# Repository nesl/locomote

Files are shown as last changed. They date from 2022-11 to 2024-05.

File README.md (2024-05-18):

# LocoMote: AI-driven Sensor Tags for Fine-Grained Undersea Localization and Sensing

hardware_setup
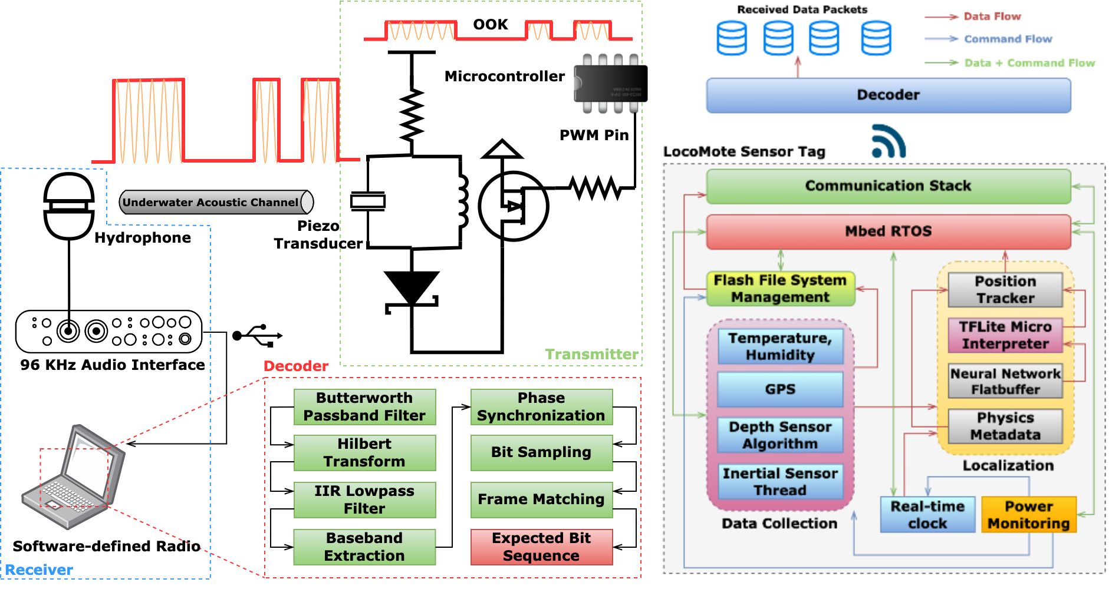
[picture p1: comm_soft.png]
software_setup


## Paper
https://ieeexplore.ieee.org/abstract/document/10494218/

## Summary
Long-term and fine-grained maritime localization and sensing is challenging due to sporadic connectivity, constrained power budget, limited footprint, and hostile environment. In this paper, we present the design considerations and implementation of LocoMote, a rugged ultra-low-footprint undersea sensor tag with on-device AI-driven localization, online communication, and energy-harvesting capabilities. LocoMote uses on-chip (< 30 kB) neural networks to track underwater objects within 3 meters with ~6 minutes of GPS outage from 9DoF inertial sensor readings. The tag streams data at 2-5 kbps (< 10^-3 bit error rate) using piezo-acoustic ultrasonics, achieving underwater communication range of more than 50 meters while allowing up to 55 nodes to concurrently stream via randomized time-division multiple access. To recharge the battery during sleep, the tag uses an aluminum-air salt water energy harvesting system, generating upto 5 mW of power. LocoMote is ultra-lightweight (< 50 grams), tiny (32x32$x10 mm^3), consumes low power (~330 mW peak), and comes with a suite of high-resolution sensors. We highlight the hardware and software design decisions, implementation lessons, and the real-world performance of our tag versus existing oceanic sensing technologies. 

## Code Architecture
- ```encasement```: contains the ```.stl``` CAD files for the EPU-40 encasement and resin base.
- ```pcb```: contains the altium pcb design files for the main circuit board, and eagle pcb design files for the offline battery charger and pressure sensor board. PCB schematic and board design images are also provided.
- ```software```: contains code for: (a) data logging from all the sensors into the flash, also contains code to toggle data recovery modes from a computer using a Python script (```data_logger_demo```); (b) communication stack for the transmitter and receiver (```piezo_OOK_demo```); (c) PWM demo for piezo (```piezo_PWM_demo```); (d) GPS data logging and power measurement (```GPS```); (e) repository link for developing neural inertial navigation algorithms, as well as Marina Del Rey deployment IMU, GPS dataset; an importer is provided for the dataset (```neural_inertial_navigation```).

## Required items
- Altium Designer (21.x.x or higher) (https://www.altium.com/altium-designer/).
- AutoDesk Eagle (9.6.2 or higher) (https://www.autodesk.com/products/eagle/overview)
- TinkerCad (https://www.tinkercad.com/).
- For developing neural inertial navigation algorithms, check the requirements in ```software/neural_inertial_navigation/tinyodom```.
- MATLAB with all toolboxes installed (R2020a or better).
- Arduino IDE (https://www.arduino.cc/en/software/) with STM32 Core installed (https://github.com/stm32duino/Arduino_Core_STM32). The Arduino libraries required are listed in ```software/arduino_lib_links.txt```.
- Audacity (https://www.audacityteam.org/)
- Hardware: Check the pcb design files and the paper for list of hardware required and purchase links.

## Citation
Please cite this as:

Swapnil Sayan Saha, Caden Davis, Sandeep Singh Sandha, Junha Park, Joshua Geronimo, Luis Antonio Garcia and Mani Srivastava, "LocoMote: AI-driven Sensor Tags for Fine-Grained Undersea Localization and Sensing", in IEEE Sensors Journal, vol. 24, no. 10, pp. 16999-17018, 15 May 2024, IEEE.

## Acknowledgements
 This work was sponsored in part by: the IoBT REIGN Collaborative Research Alliance funded by the Army Research Laboratory under Cooperative Agreement W911NF-17-2-0196; the Air Force Office of Scientific Research under award FA9550-22-1-0193; the CONIX Research Center, one of the centers in Joint University Microelectronics Program, a Semiconductor Research Corporation program sponsored by the Defense Advanced Research Projects Agency; and, the King Abdullah University of Science and Technology through its Sensor Innovation research program.

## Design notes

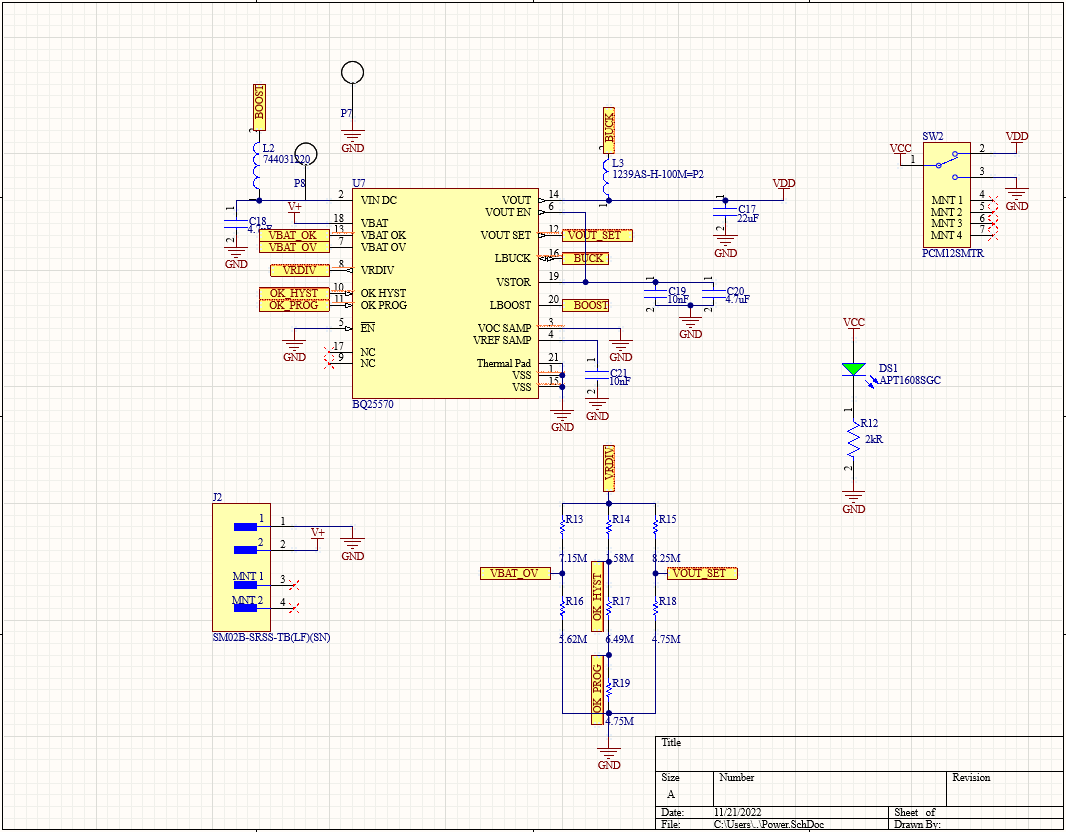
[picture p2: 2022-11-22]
pcb/schematic images/power_schematic.PNG

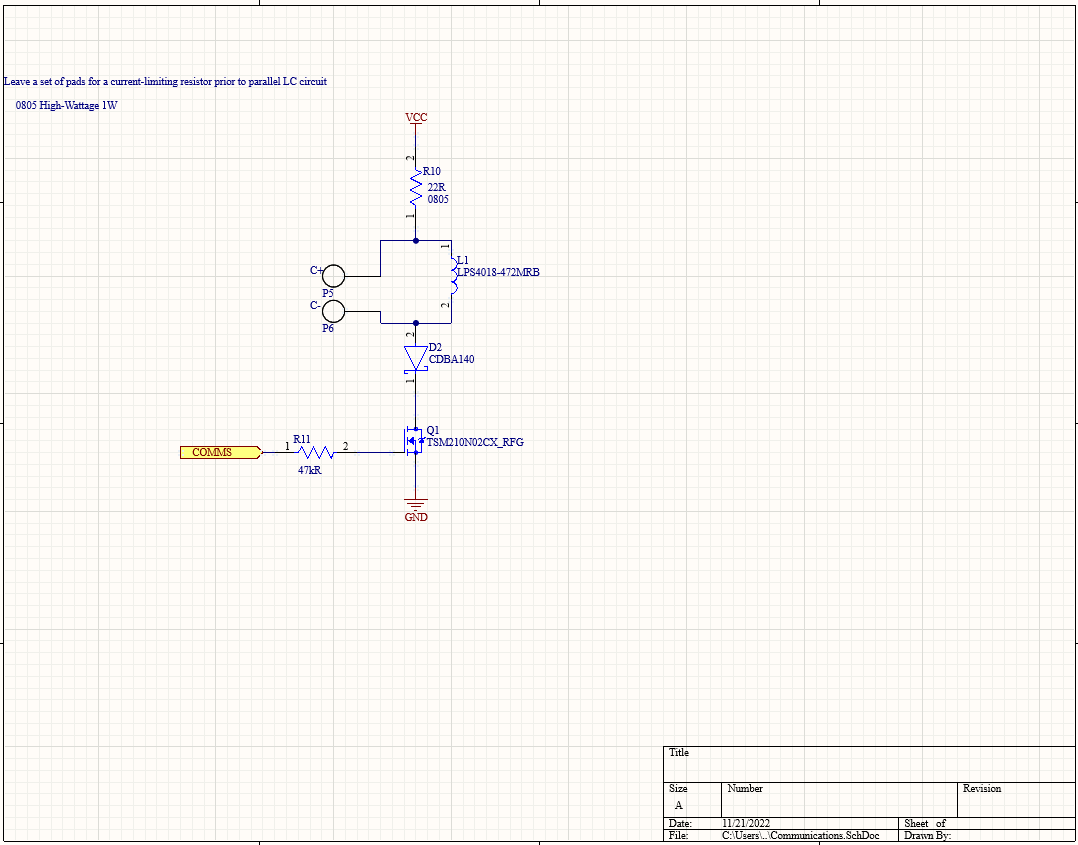
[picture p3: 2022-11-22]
pcb/schematic images/communications_schematic.PNG

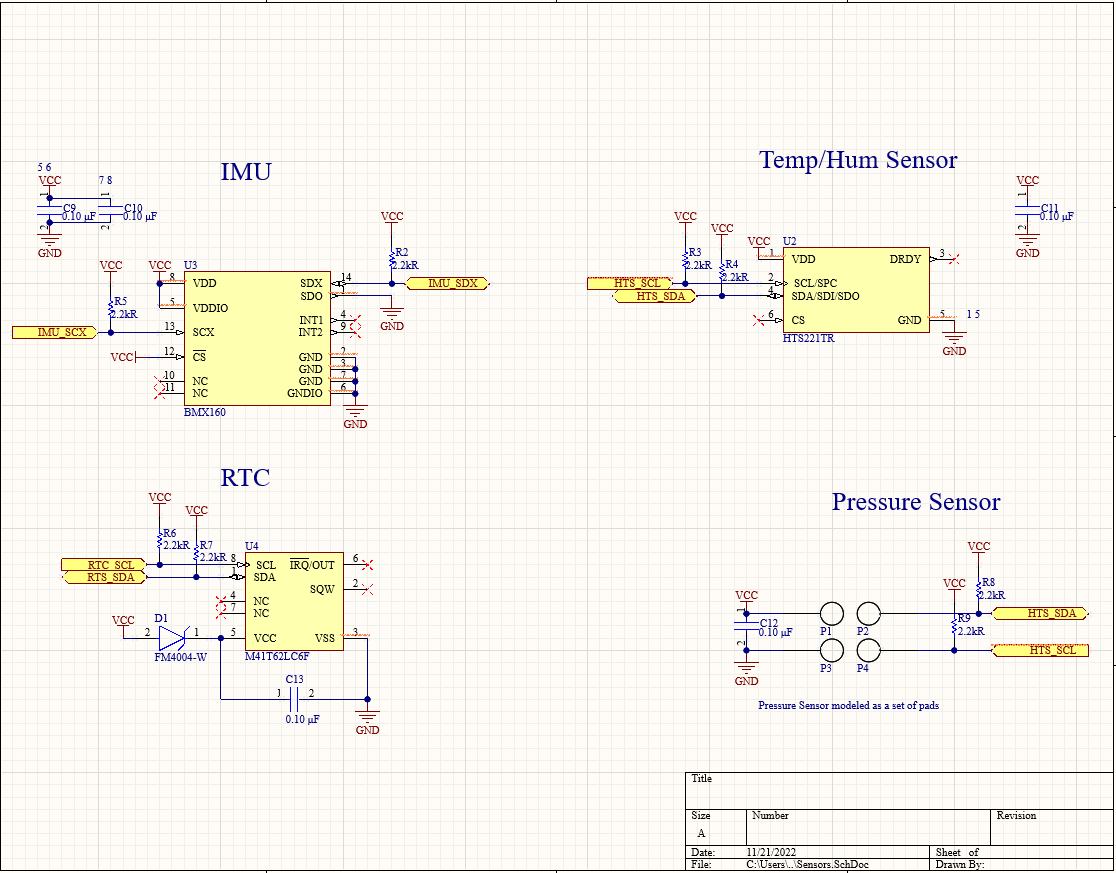
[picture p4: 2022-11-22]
pcb/schematic images/sensors_schematic.PNG

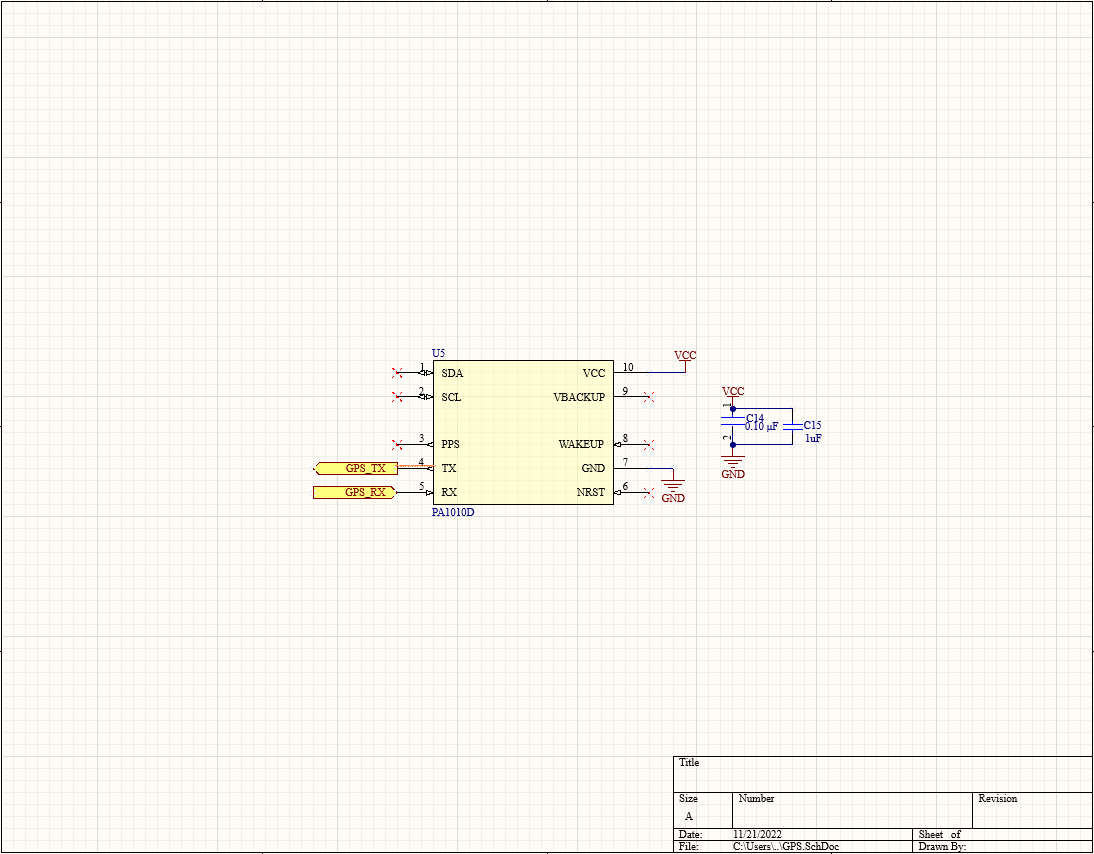
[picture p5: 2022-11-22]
pcb/schematic images/gps_schematic.PNG

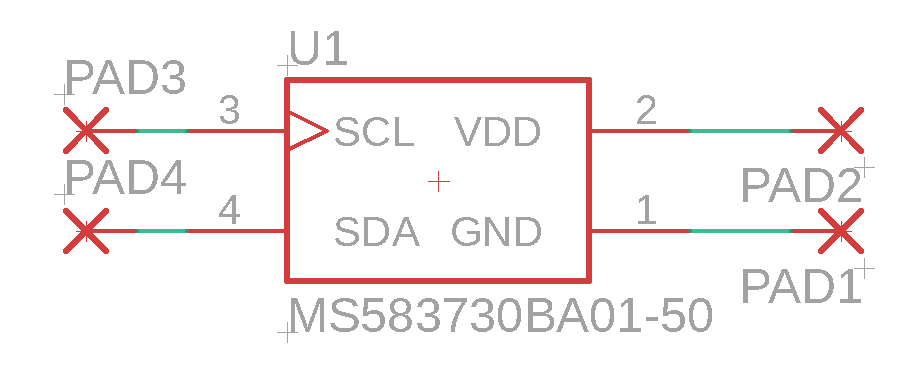
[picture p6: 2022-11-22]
pcb/schematic images/pressure_schematic.png

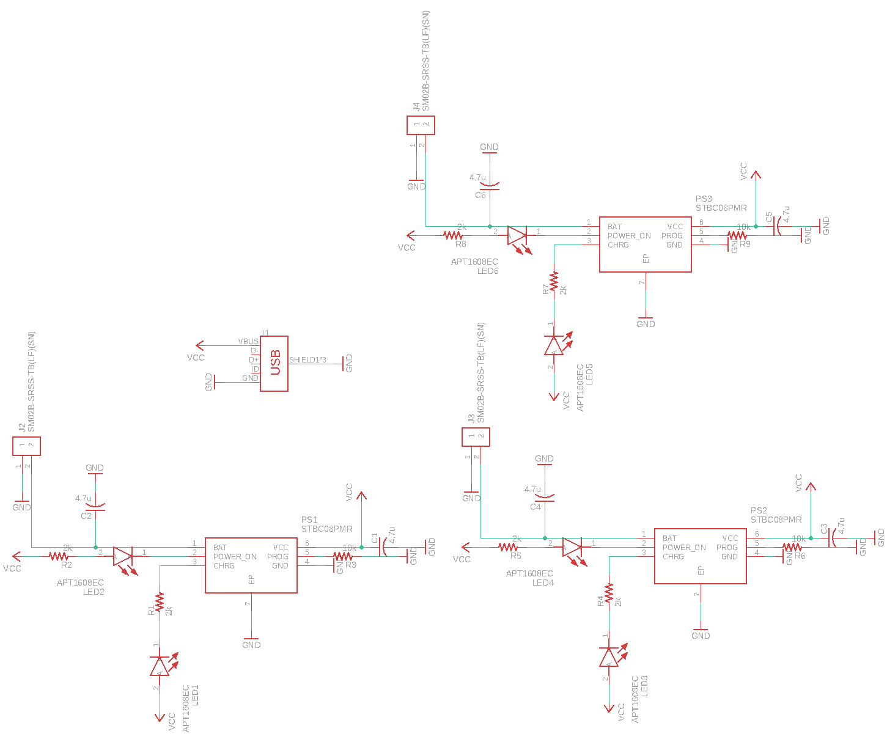
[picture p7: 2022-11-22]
pcb/schematic images/bat_charger_schematic.png

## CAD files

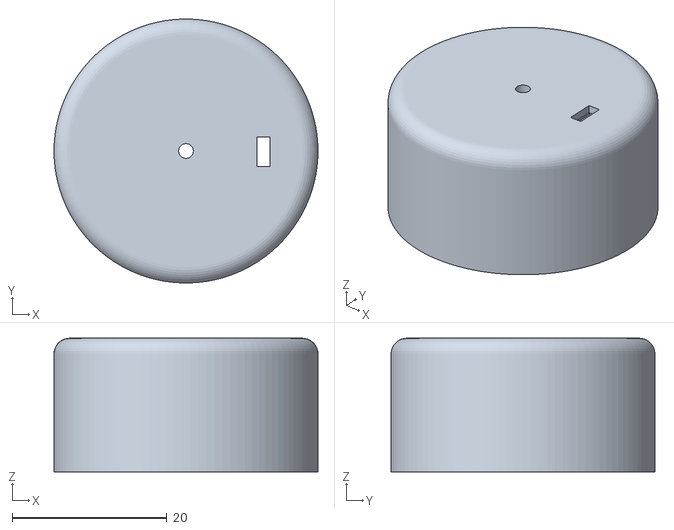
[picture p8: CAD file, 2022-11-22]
encasement/EPU40_case.stl
34.1 x 34.1 x 17.3

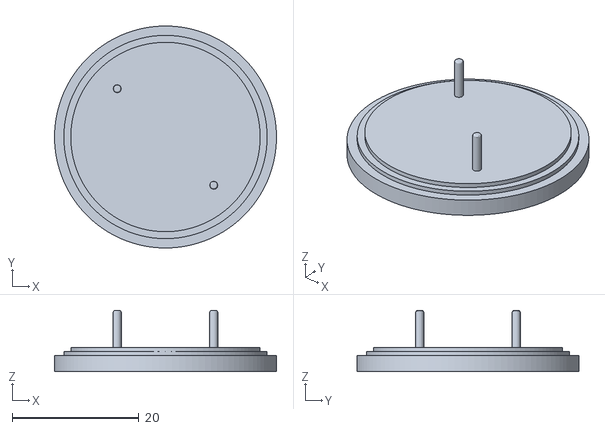
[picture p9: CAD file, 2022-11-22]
encasement/Base.stl
35.1 x 35.1 x 9.65

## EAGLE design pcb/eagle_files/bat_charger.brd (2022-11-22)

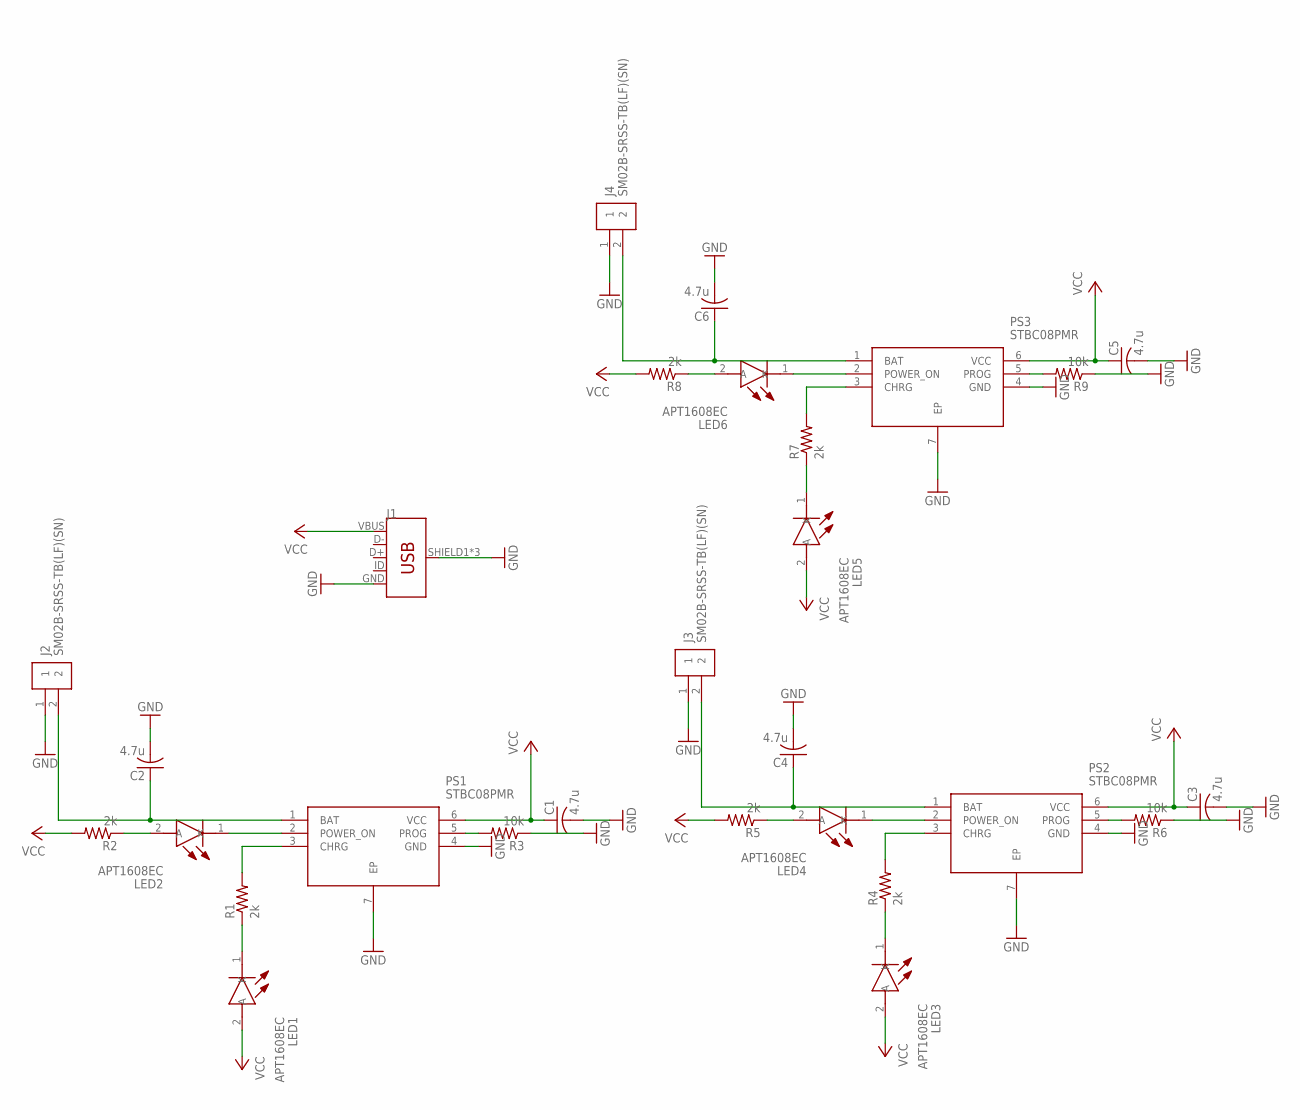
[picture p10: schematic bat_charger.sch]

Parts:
C1, C2, C3, C4, C5, C6: 4.7u; C0603
J1: USB_MICRO-B_FEMALE-SMT; USB-B-MICRO-SMD
J2, J3, J4: SM02B-SRSS-TB(LF)(SN)
LED1, LED2, LED3, LED4, LED5, LED6: APT1608EC; LEDC1608X85N
PS1, PS2, PS3: STBC08PMR; SON95P300X300X100-7N
R1, R2, R4, R5, R7, R8: 2k; R0603
R3, R6, R9: 10k; R0603

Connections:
GND: C1.2, C2.2, C3.2, C4.2, C5.2, C6.2, J1.GND, J1.SHIELD1 (SHIELD), J1.SHIELD2 (SHIELD), J1.SHIELD3 (SHIELD), J2.1, J3.1, J4.1, PS1.4 (GND), PS1.7 (EP), PS2.4 (GND), PS2.7 (EP), PS3.4 (GND), PS3.7 (EP), R3.1, R6.1, R9.1
unnamed: PS1.3 (CHRG), R1.2
unnamed: LED1.1 (K), R1.1
unnamed: C2.1, J2.2, PS1.1 (BAT)
unnamed: LED2.1 (K), PS1.2 (POWER_ON)
unnamed: LED2.2 (A), R2.1
unnamed: PS1.5 (PROG), R3.2
unnamed: PS2.3 (CHRG), R4.2
unnamed: LED3.1 (K), R4.1
unnamed: LED4.1 (K), PS2.2 (POWER_ON)
unnamed: LED4.2 (A), R5.1
unnamed: PS2.5 (PROG), R6.2
unnamed: C4.1, J3.2, PS2.1 (BAT)
unnamed: PS3.3 (CHRG), R7.2
unnamed: LED5.1 (K), R7.1
unnamed: LED6.1 (K), PS3.2 (POWER_ON)
unnamed: LED6.2 (A), R8.1
unnamed: PS3.5 (PROG), R9.2
unnamed: C6.1, J4.2, PS3.1 (BAT)
VCC: C1.1, C3.1, C5.1, J1.VBUS, LED1.2 (A), LED3.2 (A), LED5.2 (A), PS1.6 (VCC), PS2.6 (VCC), PS3.6 (VCC), R2.2, R5.2, R8.2

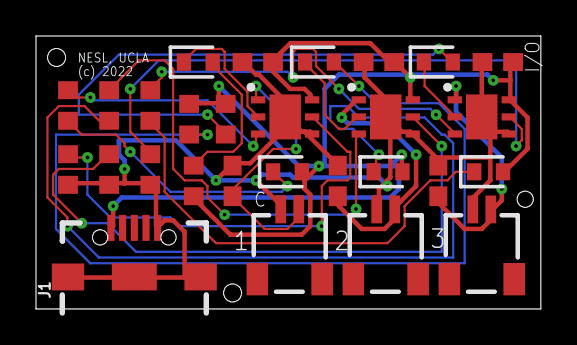
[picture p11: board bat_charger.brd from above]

Board: 2 copper layers, 28.0 x 15.2 mm, 28 parts (0 on the bottom side), 20 nets.

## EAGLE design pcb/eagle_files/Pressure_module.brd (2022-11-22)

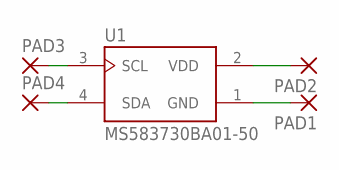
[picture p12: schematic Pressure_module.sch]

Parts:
PAD1, PAD2, PAD3, PAD4: 1,6/0,8
U1: MS583730BA01-50; TE_MS583730BA01-50

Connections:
unnamed: PAD3.1, U1.3 (SCL)
unnamed: PAD4.1, U1.4 (SDA)
unnamed: PAD2.1, U1.2 (VDD)
unnamed: PAD1.1, U1.1 (GND)

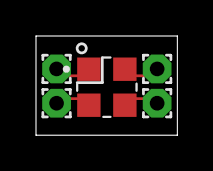
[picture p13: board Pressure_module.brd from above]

Board: 2 copper layers, 7.9 x 5.5 mm, 5 parts (0 on the bottom side), 4 nets.

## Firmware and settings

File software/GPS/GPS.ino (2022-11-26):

#include <Adafruit_GPS.h>
#include <Wire.h>
#include <Adafruit_INA219.h>

Adafruit_INA219 ina219;

Adafruit_GPS GPS(&Wire);

#define GPSECHO true

int timer = 0;

void setup() {
  Serial.begin(115200);
  while (!Serial) {
    delay(100);
  }
  Wire.begin();
  uint32_t currentFrequency;
  if (!ina219.begin()) {
    Serial.println("Failed to find INA219 chip");
    while (1) { delay(10); }
  }
  ina219.setCalibration_16V_400mA();
  
  GPS.begin(0x10);

  GPS.sendCommand(PMTK_SET_NMEA_OUTPUT_RMCGGA);
  GPS.sendCommand(PMTK_SET_NMEA_UPDATE_1HZ);
  GPS.sendCommand(PGCMD_ANTENNA);

  delay(1000);
}

void readPA1010D() {
  GPS.read();
  if (GPS.newNMEAreceived()) {
    Serial.println(GPS.lastNMEA());
    Serial.print("Fix: "); Serial.println(GPS.fix);
    GPS.parse(GPS.lastNMEA());
  }
}

void startPA1010D() {
  do {
    readPA1010D();
    // Serial.println("Waiting for fix...");
    // delay(50);
  } while (!GPS.fix);
  Serial.println("Fix acquired");
}

void sleepPA1010D() {
  GPS.standby();
}

void wakeupPA1010D() {
  GPS.wakeup();
}

void readPower() {
  float power_mW = 0;
  power_mW = ina219.getPower_mW();
  Serial.print("Power:         "); Serial.print(power_mW); Serial.println(" mW");
}


void loop() {
  // put your main code here, to run repeatedly:
  Serial.println("Testing Start");
  
  wakeupPA1010D();
  
  // Test 1: Cold Start (getting a fix aka Acquisition)
  Serial.println("Cold start test");
  readPower();
  startPA1010D();
  readPower();
  delay(5000);

  Serial.println("Warm start test");
  // sleepPA1010D();
  // delay(2000);
  // wakeupPA1010D();
  delay(2000);
  readPower();
  startPA1010D();
  readPower();
  delay(5000);
  
  
  // Test 2: Active (maintaining a fix aka Tracking)
  Serial.println("Active test");
  readPower();
  readPA1010D();
  readPower();
  Serial.println("---");
  delay(500);
  readPower();
  readPA1010D();
  readPower();
  Serial.println("---");
  delay(500);
  readPower();
  readPA1010D();
  readPower();
  Serial.println("---");
  delay(500);
  readPower();
  readPA1010D();
  readPower();
  Serial.println("---");
  delay(500);
  
  
  // Test 4: Sleep
  Serial.println("Sleep test");
  sleepPA1010D();
  delay(2000);
  readPower();
  delay(2000);
  readPower();
  delay(2000);
  
  Serial.println("Testing done");
}

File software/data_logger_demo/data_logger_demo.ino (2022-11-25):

// INCLUDES

#include <Wire.h>
#include <Adafruit_Sensor.h>
#include <DPEng_BMX160.h>
#include <SerialFlash.h>
#include <SPI.h>
#include <stdlib.h>
#include "mbed.h"
#include <Adafruit_HTS221.h>
#include <Adafruit_Sensor.h>

// DEFINES

#define PWM_PIN               3
#define PWM_FREQUENCY         22500
#define BIT_RATE              5

#define MOSI              D11
#define MISO              D12
#define SCK               D13
#define CS                D10

#define MODE_SELECT_PIN   D7

#define ERASE false

// initialize sensor constructs and PWM pin
DPEng_BMX160 BMX160sensor = DPEng_BMX160(0x160A, 0x160B, 0x160C);

MS5837 MS5837sensor;

Adafruit_HTS221 hts;

mbed::PwmOut pwmPin( digitalPinToPinName( PWM_PIN ) );

// variables/functions to help with flash

uint32_t fileSize = !;
uint32_t filePosition = 0;

char filename[32];

char flashBuffer[256]; // buffer of data to be written to flash with next function call

void updateFilename();
void setRegister(uint32_t index, uint32_t value); // set value of non-volative backup register
uint32_t getRegister(uint32_t index);
bool eraseFileContent(const char* filename); // erase file on flash to regain storage

// GLOBAL SENSOR DATA CONSTRUCTS

struct BMX160data {
  float x;
  float y;
  float z;
} accel, gyro, magneto;

struct MS5837data {
  float pressure; // mbar
  float temperature; // deg C
  float depth; // m
  float altitude; // m above sea level
} temppres;

struct HTS221data {
  float temperature;
  float humidity;
} temphum;

void setup(void)
{
  // BEGIN ALL SENSORS, PINS, AND FLASH
  
  pwmPin.period( 1.0 / PWM_FREQUENCY ); // set pwm pin frequency
  pinMode(MODE_SELECT_PIN, INPUT);
  
  Serial.begin(115200);
  while (!Serial) {
    delay(100);
  }

  while (!BMX160sensor.begin(BMX160_ACCELRANGE_4G, GYRO_RANGE_250DPS)) {
    delay(100);
  }

  while (!MS5837sensor.init()) {
    delay(100);
  }
  
  MS5837sensor.setModel(MS5837::MS5837_30BA);
  MS5837sensor.setFluidDensity(997);

  while (!hts.begin_I2C()) {
    delay(100);
  }
  
  hts.setDataRate(HTS221_RATE_1_HZ);

  // setup for backup registers
  #ifdef HAL_PWR_MODULE_ENABLED
    /* Allow access to Backup domain */
    HAL_PWR_EnableBkUpAccess();
  #endif
  #ifdef __HAL_RCC_BKP_CLK_ENABLE
    /* Enable BKP CLK for backup registers */
    __HAL_RCC_BKP_CLK_ENABLE();
  #endif

  // configure SPI
  SPI.setMOSI(MOSI);
  SPI.setMISO(MISO);
  SPI.setSCLK(SCK);
  SerialFlash.begin(CS);

  // erase the flash (optional)
  if (ERASE) {
    Serial.println("Erasing Flash..."); SerialFlash.eraseAll();
    // reset the backup register value to 0 (optional)
    setRegister(1, 0);
  }

  while (!SerialFlash.ready()) {
    delay(100);
  }

  // create new file to which data will be written
  
  filename = updateFilename(filename);
  if (SerialFlash.exists(filename)) {
    // SerialFlash.remove(filename);  // It doesn't reclaim the space, but it does let you create a new file with the same name.
    eraseFileContent(filename);
  }
  
  if (!SerialFlash.createErasable(filename, fileSize)) {
    Serial.println("Flash is full!");
    exit(1);
  }
}

// BMX160 Functions
void readBMX160() { // (BMX160data& accel, BMX160data& gyro, BMX160data& magneto)
  sensors_event_t aevent, gevent, mevent;

  // get a sensor event
  BMX160sensor.getEvent(&aevent, &gevent, &mevent);

  // form of output
  accel.x = aevent.acceleration.x; // m/s^2
  accel.y = aevent.acceleration.y;
  accel.z = aevent.acceleration.z;
  gyro.x = gevent.gyro.x; // g
  gyro.y = gevent.gyro.y;
  gyro.z = gevent.gyro.z;
  magneto.x = mevent.magnetic.x; // uT
  magneto.y = mevent.magnetic.y;
  magneto.z = mevent.magnetic.z;
}

// control for activity states
void sleepBMX160() {
  BMX160sensor.standby(true);
}

void wakeBMX160() {
  BMX160sensor.standby(false);
}

// HTS221 Functions
void readHTS221() {
  sensors_event_t temp;
  sensors_event_t humidity;
  hts.getEvent(&humidity, &temp);
  temphum.temperature = temp; // degrees C
  temphum.humidity = humidity; // % rH (relative humidity)
}

void sleepHTS221() {
  // PD bit 7 for Ctrl Reg 1 set to zero
  hts.setActive(false);
}

void wakeupHTS221() {
  // PD bit 7 for Ctrl Reg 1 set to one
  hts.setActive(true);
}

// MS5837-30BA Functions
void readMS5837() {
  // form of output
  temppres.pressure = MS5837sensor.pressure(); // mbar
  temppres.temperature = MS5837sensor.temperature(); // deg C
  temppres.depth = MS5837sensor.depth(); // m
  temppres.altitude = MS5837sensor.altitude(); // m above sea level
}

// Flash Functions
bool writeBufferToFile(SerialFlashFile file) {
  if (file) {
    file.seek(filePosition);
    filePosition += 256;
    file.write(flashBuffer, 256);
    file.close();
    return true;
  } else {
    Serial.println("Error opening file");
    return false;
  }
}

bool eraseFileContent(const char* filename) {
  SerialFlashFile file;
  file = SerialFlash.open(filename);
  if (file) {
    file.erase();
    return true;
  } else {
    Serial.println("Error opening file");
    return false;
  }
}

bool writeBMX160ToFile(const char* filename) {
  SerialFlashFile file;
  file = SerialFlash.open(filename);
  if (file) {
    // convert sensor readings from float to char array (C-string)
    char accel_x[16];
    dtostrf(accel.x, 4, 3, accel_x);
    char accel_y[16];
    dtostrf(accel.y, 4, 3, accel_y);
    char accel_z[16];
    dtostrf(accel.z, 4, 3, accel_z);

    char gyro_x[16];
    dtostrf(gyro.x, 4, 3, gyro_x);
    char gyro_y[16];
    dtostrf(gyro.y, 4, 3, gyro_y);
    char gyro_z[16];
    dtostrf(gyro.z, 4, 3, gyro_z);

    char magneto_x[16];
    dtostrf(magneto.x, 4, 3, magneto_x);
    char magneto_y[16];
    dtostrf(magneto.y, 4, 3, magneto_y);
    char magneto_z[16];
    dtostrf(magneto.z, 4, 3, magneto_z);

    // create message
    strcpy(flashBuffer, "accel_x: "); // use strcpy instead of strcat to clear the buffer
    strcat(flashBuffer, accel_x);
    strcat(flashBuffer, ", accel_y: ");
    strcat(flashBuffer, accel_y);
    strcat(flashBuffer, ", accel_z: ");
    strcat(flashBuffer, accel_z);
    strcat(flashBuffer, "\n");
    strcat(flashBuffer, "gyro_x: ");
    strcat(flashBuffer, gyro_x);
    strcat(flashBuffer, ", gyro_y: ");
    strcat(flashBuffer, gyro_y);
    strcat(flashBuffer, ", gyro_z: ");
    strcat(flashBuffer, gyro_z);
    strcat(flashBuffer, "\n");
    strcat(flashBuffer, "magneto_x: ");
    strcat(flashBuffer, magneto_x);
    strcat(flashBuffer, ", magneto_y: ");
    strcat(flashBuffer, magneto_y);
    strcat(flashBuffer, ", magneto_z: ");
    strcat(flashBuffer, magneto_z);
    strcat(flashBuffer, "\n");

    // write buffer
    return writeBufferToFile(file);
  } else {
    return false;
  }
}
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

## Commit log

2022-11-22 added mech pcb soft
    [Base.stl, Communications.SchDoc, EPU40_case.stl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]
2022-11-22 added bat charger and pressure boards
    [Pressure_module.brd, Pressure_module.sch, bat_charger.brd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]

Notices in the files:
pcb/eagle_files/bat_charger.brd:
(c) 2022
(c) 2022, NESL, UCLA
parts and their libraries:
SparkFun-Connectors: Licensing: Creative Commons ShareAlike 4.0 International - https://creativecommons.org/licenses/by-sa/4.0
